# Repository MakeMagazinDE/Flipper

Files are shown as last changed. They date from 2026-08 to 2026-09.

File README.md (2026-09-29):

GitHub Logo

Maker Media GmbH

***

# The Blue Mermaid – Tragbares Flipperspiel

### Ein selbstgebauter Flipper mit ESP32, WS2812B-LEDs, Laser-Lichtschranke und Sound – ein Projekt für Groß und Klein.

Ein tragbares Flipperspiel für ein Festival zu bauen – das allein ist schon eine Herausforderung. Noch schwieriger wird es, wenn die eigenen Kinder mitbauen sollen. Wie das gelingt, wird im Artikel in der Make 5/26 beschrieben.

Im gedruckten Schaltplan (Bild 9, S. 24) sind die Lautsprecher falsch angeschlossen. Sie dürfen nicht mit VCC oder GND verbunden werden. Der DFPlayer Mini hat einen eingebauten Verstärker — beide Lautsprecher werden ausschließlich zwischen SPK_1 und SPK_2 angeschlossen (parallel, ohne externe Stromversorgung). Der korrigierte Schaltplan liegt hier im Repository.

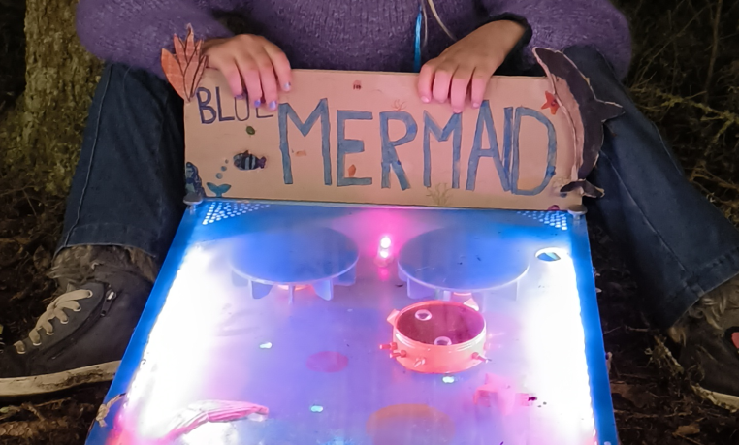
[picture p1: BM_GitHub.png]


Der vollständige Artikel zum Projekt steht in der [Make-Ausgabe 5/26](https://www.heise.de/select/make/2026/5). Hier finden Sie den Arduino-Sketch, die Lasercutter-Vorlagen und die 3D-Druckdateien.

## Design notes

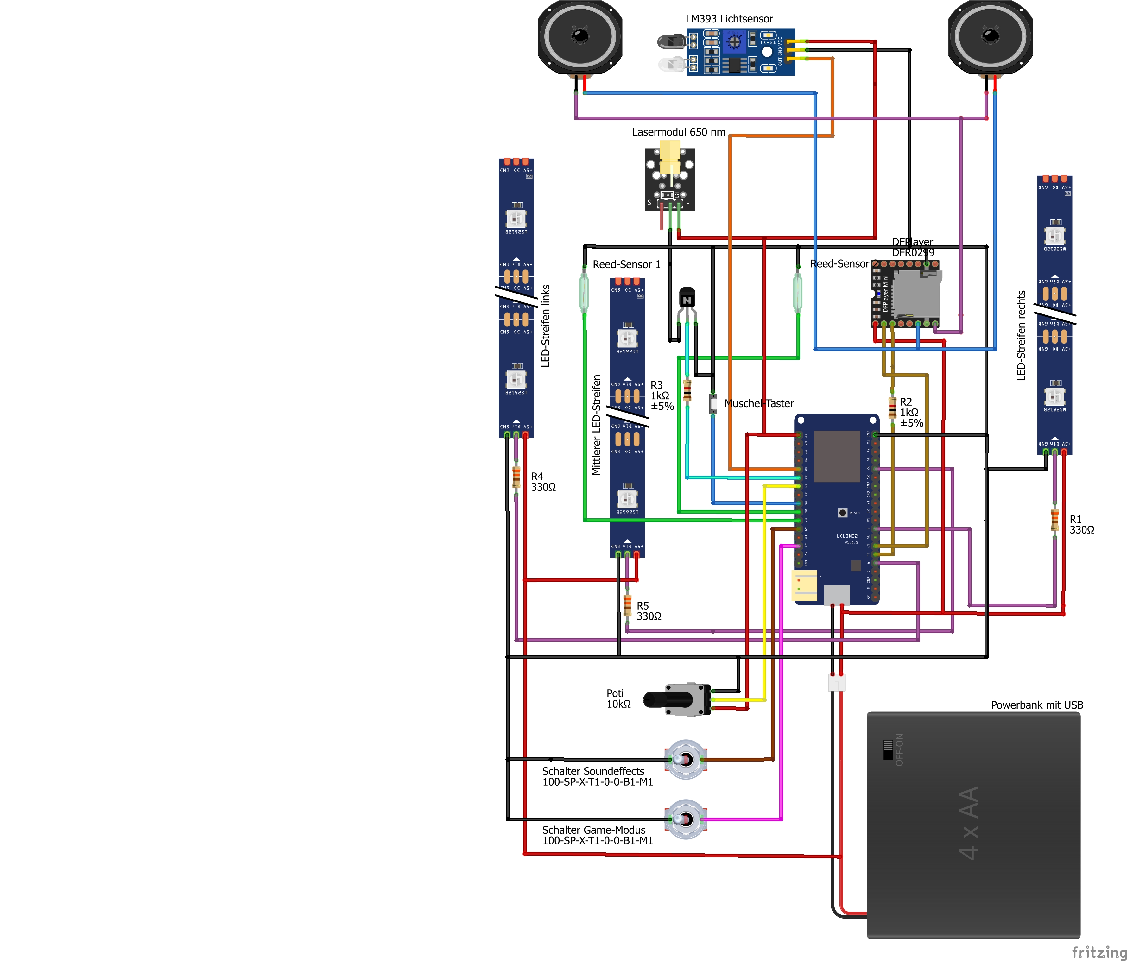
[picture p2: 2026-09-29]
Schaltung-Flipper_Steckplatine_KORRIGIERT.jpg

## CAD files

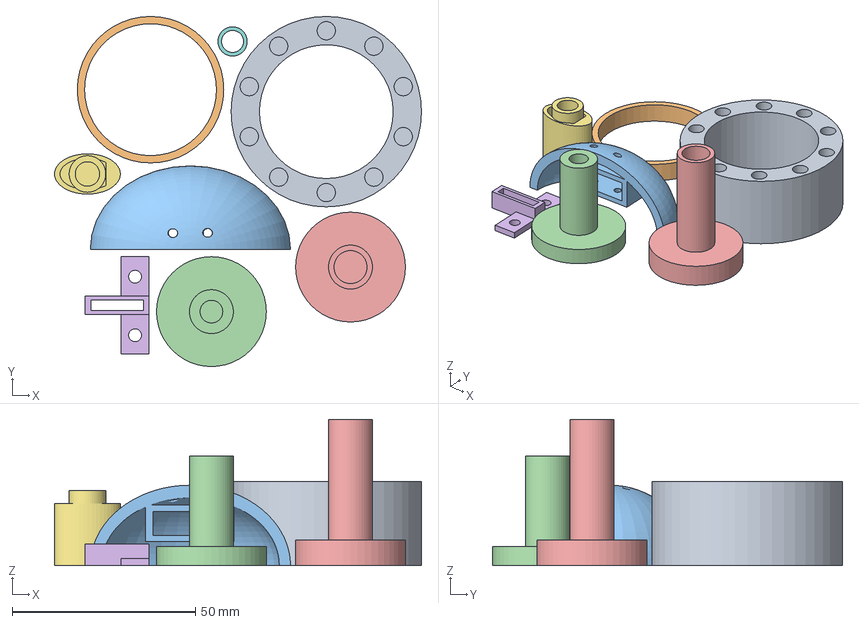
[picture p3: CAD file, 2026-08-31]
Flipper - 3D-Druck - alle Teile zusammen.3mf
100.2 x 95.6 x 40.0 mm
Flipper2.4- ring magnethalter 10 löcher.stl
lautsprecher ring.stl
Muschelhalterung.stl
seppos ding halterung.stl
Flipper Button.stl
Flipper - Reed Sensor Halterung.stl
Laser Halterung.stl
Hülse 6-8 mm 10 hoch.stl

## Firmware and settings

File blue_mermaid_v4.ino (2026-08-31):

// ============================================================
// THE BLUE MERMAID — Portable Pinball Game  v4
// Lolin D32 + DFPlayer Mini
// Main strip: 26 WS2812B  |  Side strips: 35+35 WS2812B
// Total: 96 LEDs
// ============================================================
//
// Libraries (Arduino Library Manager):
//   - FastLED
//   - DFRobotDFPlayerMini
//
// Board: "LOLIN D32" or "ESP32 Dev Module"
//
// SD card (FAT32, files in root):
//   001.mp3  — Seashell chime
//   002.mp3  — Wheel tick slow
//   003.mp3  — Wheel tick medium
//   004.mp3  — Wheel tick fast
//   005.mp3  — Top gate whoosh/splash
//   006.mp3  — Combo fanfare (3+ hits)
//   007.mp3  — Jackpot fanfare (5+ hits)
//
// ============================================================
// WIRING
// ============================================================
//
// POWER — USB power bank:
//   Power bank USB-A 5V  → LED strips VCC (all three)
//   Power bank USB-A GND → LED strips GND (all three)
//   Power bank           → Lolin micro-USB (powers board)
//   Lolin 3V3            → Laser VCC, Light sensor VCC
//
//   Do NOT route LED power through the board!
//   Common GND between power bank, board, and all modules.
//
// MAIN STRIP (26 LEDs, one chain, clockwise from top-right):
//   GPIO 22 → strip DI  (330Ω resistor recommended)
//   Segment order:
//     #1  Upper right corner    3 LEDs  (idx  0– 2)
//     #2  Under right wheel     2 LEDs  (idx  3– 4)
//     #3  Lower middle singles  7 LEDs  (idx  5–11)
//     #4  Bottom right corner   3 LEDs  (idx 12–14)
//     #5  Bottom left corner    3 LEDs  (idx 15–17)
//     #6  Seashell              3 LEDs  (idx 18–20)
//     #7  Under left wheel      2 LEDs  (idx 21–22)
//     #8  Upper left corner     3 LEDs  (idx 23–25)
//
// LEFT SIDE STRIP (35 LEDs, bottom to top):
//   GPIO 4 → strip DI  (330Ω resistor recommended)
//
// RIGHT SIDE STRIP (35 LEDs, bottom to top):
//   GPIO 5 → strip DI  (330Ω resistor recommended)
//
// DFPlayer Mini:
//   GPIO 16 (TX2) → DFPlayer RX  (via 1kΩ resistor!)
//   GPIO 17 (RX2) → DFPlayer TX
//   DFPlayer VCC  → 5V (from power bank)
//   DFPlayer GND  → GND
//   SPK1/SPK2     → 8Ω speaker(s)
//
// SEASHELL SWITCH:
//   GPIO 25 → taster → GND  (INPUT_PULLUP)
//
// WHEEL REED SENSORS (5 magnets, 72° apart):
//   GPIO 26 → left reed sensor → GND
//   GPIO 27 → right reed sensor → GND
//   Mounting: reed long axis tangential, 2–4mm gap.
//
// LASER LICHTSCHRANKE (top gate):
//   GPIO 32 → Light sensor module DO
//   GPIO 33 → 1kΩ → BC337 pin 2 (Base)
//
//   BC337 (TO-92, flat side facing you):
//     Pin 1 (left)   = COLLECTOR → Laser GND wire
//     Pin 2 (center) = BASE     → 1kΩ → GPIO 33
//     Pin 3 (right)  = EMITTER  → GND
//     Laser VCC → 3V3
//
// RESET BUTTON (existing on board):
//   GPIO 2 → taster → GND  (INPUT_PULLUP)
//
// ============================================================

#include <FastLED.h>
#include <DFRobotDFPlayerMini.h>
#include <WiFi.h>
#include <WebServer.h>
#include <DNSServer.h>
#include <Preferences.h>

Preferences prefs;

// ----- Pin definitions -----
#define PIN_MAIN_LED      22
#define PIN_SIDE_L_LED     4
#define PIN_SIDE_R_LED     5
#define PIN_RESET_BTN      2
#define PIN_SEASHELL      25
#define PIN_WHEEL_L       26
#define PIN_WHEEL_R       27
#define PIN_GATE_SENSOR   32
#define PIN_LASER         33
#define DFPLAYER_TX       16
#define DFPLAYER_RX       17
#define PIN_BRIGHT_POT    34    // Potentiometer for brightness (ADC1)
#define PIN_GAME_TOGGLE   13    // Locking switch: ON=playing, OFF=attract
#define PIN_SOUND_TOGGLE  14    // Locking switch: each flip plays next sound

#define SND_EXTRA_START    8    // First extra sound track number on SD card
#define SND_EXTRA_COUNT   10    // Number of extra sound files (008.mp3 - 017.mp3)

// ----- LED counts -----
#define NUM_MAIN          26
#define NUM_SIDE          35    // Per side strip

// ----- Main strip segment indices (clockwise from top-right) -----
#define CORNER_UR_START    0    // #1 Upper right corner
#define CORNER_UR_END      2    //     3 LEDs

#define WHEEL_R_START      3    // #2 Under right wheel
#define WHEEL_R_END        4    //     2 LEDs

#define HOLES_START        5    // #3 Lower middle singles
#define HOLES_END         11    //     7 LEDs

#define CORNER_BR_START   12    // #4 Bottom right corner
#define CORNER_BR_END     14    //     3 LEDs

#define CORNER_BL_START   15    // #5 Bottom left corner
#define CORNER_BL_END     17    //     3 LEDs

#define SHELL_START       18    // #6 Seashell
#define SHELL_END         20    //     3 LEDs

#define WHEEL_L_START     21    // #7 Under left wheel
#define WHEEL_L_END       22    //     2 LEDs

#define CORNER_UL_START   23    // #8 Upper left corner
#define CORNER_UL_END     25    //     3 LEDs

// ----- Sound tracks -----
#define SND_SHELL_CHIME    1
#define SND_WHEEL_SLOW     2
#define SND_WHEEL_MED      3
#define SND_WHEEL_FAST     4
#define SND_TOP_GATE       5
#define SND_COMBO_FANFARE  6
#define SND_JACKPOT        7

// ----- Timing -----
#define COMBO_WINDOW_MS      2500
#define REED_DEBOUNCE_MS       10
#define GATE_DEBOUNCE_MS        5
#define SHELL_DEBOUNCE_MS     200
#define RESET_DEBOUNCE_MS     500
#define WHEEL_TIMEOUT_MS      800

// Wheel speed: ms between reed pulses (5 magnets, 72° apart)
#define WHEEL_FAST_THRESH     150
#define WHEEL_MED_THRESH      300

// Effect durations
#define EFFECT_SHELL_MS       800
#define EFFECT_GATE_MS       1000
#define EFFECT_WHEEL_MS       500
#define EFFECT_COMBO_MS      1500

// Laser blink in attract mode
#define LASER_BLINK_ON_MS    2000
#define LASER_BLINK_OFF_MS    400

// ============================================================
// LED arrays
// ============================================================

CRGB mainLeds[NUM_MAIN];
CRGB sideLeds_L[NUM_SIDE];
CRGB sideLeds_R[NUM_SIDE];

DFRobotDFPlayerMini dfPlayer;
bool dfPlayerReady = false;

// ----- Game state -----
enum GameState { STATE_ATTRACT, STATE_PLAYING, STATE_DEBUG };
GameState gameState = STATE_ATTRACT;
GameState preDebugState = STATE_ATTRACT;
uint16_t score = 0;
unsigned long debugPrintMs = 0;

// ----- Switch state -----
struct SwitchState {
  uint8_t pin;
  bool lastState;
  unsigned long lastChangeMs;
  unsigned long debounceMs;
};

SwitchState sw_shell = { PIN_SEASHELL, HIGH, 0, SHELL_DEBOUNCE_MS };
SwitchState sw_reedL = { PIN_WHEEL_L,  HIGH, 0, REED_DEBOUNCE_MS };
SwitchState sw_reedR = { PIN_WHEEL_R,  HIGH, 0, REED_DEBOUNCE_MS };
SwitchState sw_gate  = { PIN_GATE_SENSOR, HIGH, 0, GATE_DEBOUNCE_MS };
SwitchState sw_reset = { PIN_RESET_BTN,   HIGH, 0, RESET_DEBOUNCE_MS };

// ----- Gate auto-calibration -----
bool gateBeamIntactState = HIGH;

// ----- Physical controls -----
bool lastGameToggle = HIGH;
bool lastSoundToggle = HIGH;
bool gameToggleActive = false;
uint8_t extraSoundIndex = 0;
unsigned long lastPotReadMs = 0;
unsigned long lastGameToggleMs = 0;
unsigned long lastSoundToggleMs = 0;

// ----- Wheel tracking -----
struct WheelTracker {
  unsigned long lastPulseMs;
  unsigned long pulseInterval;
  uint8_t pulseCount;
  uint8_t speedTier;        // 0=stopped, 1=slow, 2=med, 3=fast
  uint8_t lastSoundPlayed;
};

WheelTracker wheelL = { 0, 9999, 0, 0, 0 };
WheelTracker wheelR = { 0, 9999, 0, 0, 0 };

// ----- Combo -----
uint8_t comboCount = 0;
unsigned long lastHitMs = 0;

// ----- Active effects (main strip) -----
struct Effect {
  uint8_t type;   // 0=none 1=shell 2=wheelL 3=wheelR 4=gate 5=combo
  unsigned long startMs;
  unsigned long durationMs;
  uint8_t intensity;
};
#define MAX_EFFECTS 5
Effect effects[MAX_EFFECTS];

// ----- Side strip swoosh state -----
struct Swoosh {
  bool active;
  unsigned long startMs;
  uint8_t hue;
  uint8_t direction;    // 0=top-to-bottom, 1=bottom-to-top
  uint8_t intensity;
  uint16_t durationMs;
  uint8_t sides;        // 0=both, 1=left only, 2=right only
};
#define MAX_SWOOSHES 3
Swoosh swooshes[MAX_SWOOSHES];

// ----- Animation phase -----
uint16_t idlePhase = 0;
bool laserOn = false;
unsigned long laserToggleMs = 0;

// ----- Tunable parameters (adjustable via web, saveable to NVS) -----
uint16_t tuneGateDebounce = GATE_DEBOUNCE_MS;
uint16_t tuneReedDebounce = REED_DEBOUNCE_MS;
uint16_t tuneShellDebounce = SHELL_DEBOUNCE_MS;
uint16_t tuneWheelFast = WHEEL_FAST_THRESH;
uint16_t tuneWheelMed = WHEEL_MED_THRESH;
uint16_t tuneComboWindow = COMBO_WINDOW_MS;
uint8_t  tuneBrightness = 180;
uint16_t tuneLoopDelay = 10;

// ----- Color tuning (HSV hues, 0-255) -----
uint8_t tuneHueSlow   = 145;  // Blue
uint8_t tuneHueMed    = 24;   // Orange
uint8_t tuneHueFast   = 120;  // Cyan
uint8_t tuneHueShell  = 25;   // Warm gold
uint8_t tuneHueGate   = 130;  // Cyan-blue
uint8_t tuneHueIdle   = 140;  // Deep blue
uint8_t tuneHueAttract = 140; // Attract base hue
uint8_t tuneVolume    = 25;   // DFPlayer volume (0-30)

// ----- NVS save/load -----
void saveSettings() {
  prefs.begin("bm", false);
  prefs.putUShort("gateDb", tuneGateDebounce);
  prefs.putUShort("reedDb", tuneReedDebounce);
  prefs.putUShort("shellDb", tuneShellDebounce);
  prefs.putUShort("wFast", tuneWheelFast);
  prefs.putUShort("wMed", tuneWheelMed);
  prefs.putUShort("combo", tuneComboWindow);
  prefs.putUChar("bright", tuneBrightness);
  prefs.putUShort("loopMs", tuneLoopDelay);
  prefs.putUChar("hueSlow", tuneHueSlow);
  prefs.putUChar("hueMed", tuneHueMed);
  prefs.putUChar("hueFast", tuneHueFast);
  prefs.putUChar("hueShell", tuneHueShell);
  prefs.putUChar("hueGate", tuneHueGate);
  prefs.putUChar("hueIdle", tuneHueIdle);
  prefs.putUChar("hueAttr", tuneHueAttract);
  prefs.putUChar("vol", tuneVolume);
  prefs.putUChar("saved", 1);
  prefs.end();
  Serial.println("Settings SAVED to NVS");
}

void loadSettings() {
  prefs.begin("bm", true);
  if (prefs.getUChar("saved", 0) == 1) {
    tuneGateDebounce = prefs.getUShort("gateDb", GATE_DEBOUNCE_MS);
    tuneReedDebounce = prefs.getUShort("reedDb", REED_DEBOUNCE_MS);
    tuneShellDebounce = prefs.getUShort("shellDb", SHELL_DEBOUNCE_MS);
    tuneWheelFast = prefs.getUShort("wFast", WHEEL_FAST_THRESH);
    tuneWheelMed = prefs.getUShort("wMed", WHEEL_MED_THRESH);
    tuneComboWindow = prefs.getUShort("combo", COMBO_WINDOW_MS);
    tuneBrightness = prefs.getUChar("bright", 180);
    tuneLoopDelay = prefs.getUShort("loopMs", 10);
    tuneHueSlow = prefs.getUChar("hueSlow", 145);
    tuneHueMed = prefs.getUChar("hueMed", 24);
    tuneHueFast = prefs.getUChar("hueFast", 120);
    tuneHueShell = prefs.getUChar("hueShell", 25);
    tuneHueGate = prefs.getUChar("hueGate", 130);
    tuneHueIdle = prefs.getUChar("hueIdle", 140);
    tuneHueAttract = prefs.getUChar("hueAttr", 140);
    tuneVolume = prefs.getUChar("vol", 25);
    Serial.println("Settings LOADED from NVS");
  } else {
    Serial.println("No saved settings, using defaults");
  }
  prefs.end();

  // Apply loaded values
  FastLED.setBrightness(tuneBrightness);
  sw_gate.debounceMs = tuneGateDebounce;
  sw_reedL.debounceMs = tuneReedDebounce;
  sw_reedR.debounceMs = tuneReedDebounce;
  sw_shell.debounceMs = tuneShellDebounce;
}

// ----- Gate interrupt (catches fast ball crossings) -----
volatile bool gateISRfired = false;
volatile unsigned long gateISRtime = 0;

void IRAM_ATTR gateISR() {
  gateISRfired = true;
  gateISRtime = millis();
}

// ============================================================
// WiFi Captive Portal (debug via phone)
// ============================================================

WebServer webServer(80);
DNSServer dnsServer;
const byte DNS_PORT = 53;

unsigned long webHitShell = 0;
unsigned long webHitWheelL = 0;
unsigned long webHitWheelR = 0;
unsigned long webHitGate = 0;
bool webLaserOverride = false;
bool webLaserState = false;

void setupWiFi() {
  WiFi.softAP("BlueMermaid");
  delay(100);
  dnsServer.start(DNS_PORT, "*", WiFi.softAPIP());

  // Captive portal detection endpoints
  webServer.on("/generate_204", []() {
    webServer.sendHeader("Location", "http://192.168.4.1/");
    webServer.send(302, "text/plain", "");
  });
  webServer.on("/hotspot-detect.html", []() {
    webServer.sendHeader("Location", "http://192.168.4.1/");
    webServer.send(302, "text/plain", "");
  });
  webServer.on("/connecttest.txt", []() {
    webServer.sendHeader("Location", "http://192.168.4.1/");
    webServer.send(302, "text/plain", "");
  });
  webServer.on("/redirect", []() {
    webServer.sendHeader("Location", "http://192.168.4.1/");
    webServer.send(302, "text/plain", "");
  });
  webServer.on("/success.txt", []() {
    webServer.send(200, "text/plain", "success");
  });

  webServer.on("/", handleWebRoot);
  webServer.on("/data", handleWebData);
  webServer.on("/set", handleWebSet);
  webServer.on("/laser/on",  []() { webLaserOverride=true; webLaserState=true;  setLaser(true);  webServer.send(200, "text/plain", "on"); });
  webServer.on("/laser/off", []() { webLaserOverride=true; webLaserState=false; setLaser(false); webServer.send(200, "text/plain", "off"); });
  webServer.on("/laser/auto", []() { webLaserOverride=false; webServer.send(200, "text/plain", "auto"); });
  webServer.on("/save", []() { saveSettings(); webServer.send(200, "text/plain", "saved"); });
  webServer.on("/reset", []() {
    webHitShell=0; webHitWheelL=0; webHitWheelR=0; webHitGate=0;
    webServer.send(200, "text/plain", "ok");
  });
  webServer.onNotFound([]() {
    webServer.sendHeader("Location", "http://192.168.4.1/");
    webServer.send(302, "text/plain", "");
  });
  webServer.begin();
  Serial.print("WiFi AP: BlueMermaid @ ");
  Serial.println(WiFi.softAPIP());
}

void handleWebRoot() {
  String html = R"rawliteral(
<!DOCTYPE html>
<html>
<head>
<meta charset="utf-8">
<meta name="viewport" content="width=device-width, initial-scale=1">
<title>Blue Mermaid</title>
<style>
* { box-sizing: border-box; margin: 0; padding: 0; }
body {
  font-family: -apple-system, Arial, sans-serif;
  background: #0a1628; color: #e0e8f0;
  padding: 12px; max-width: 420px; margin: 0 auto;
}
h1 { color: #4fc3f7; font-size: 18px; text-align: center; margin-bottom: 10px; }
.card {
  background: #162040; border-radius: 10px;
  padding: 12px; margin-bottom: 10px;
  border: 1px solid #2a3a5c;
}
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
void loop() {
  unsigned long now = millis();

  dnsServer.processNextRequest();
  webServer.handleClient();

  // --- Potentiometer brightness (read every 100ms, smoothed) ---
  if ((now - lastPotReadMs) > 100) {
    lastPotReadMs = now;
    int raw = analogRead(PIN_BRIGHT_POT);
    uint8_t potBright = map(raw, 0, 4095, 10, 255);
    // Smooth: only update if change is significant (avoids ADC noise flicker)
    if (abs((int)potBright - (int)tuneBrightness) > 5) {
      tuneBrightness = potBright;
      FastLED.setBrightness(tuneBrightness);
    }
  }

  // --- Game toggle switch (locking switch, 50ms debounce) ---
  bool curGame = digitalRead(PIN_GAME_TOGGLE);
  if (curGame != lastGameToggle && (now - lastGameToggleMs) > 50) {
    lastGameToggle = curGame;
    lastGameToggleMs = now;
    gameToggleActive = (curGame == LOW);
    if (gameToggleActive && gameState == STATE_ATTRACT) {
      score = 0;
      comboCount = 0;
      lastHitMs = 0;
      wheelL = { 0, 9999, 0, 0, 0 };
      wheelR = { 0, 9999, 0, 0, 0 };
      for (int i = 0; i < MAX_EFFECTS; i++) effects[i].type = 0;
      for (int i = 0; i < MAX_SWOOSHES; i++) swooshes[i].active = false;
      gameState = STATE_PLAYING;
      setLaser(true);
    } else if (!gameToggleActive && gameState == STATE_PLAYING) {
      gameState = STATE_ATTRACT;
      setLaser(false);
    }
  }

  // --- Sound toggle switch (locking switch, 50ms debounce) ---
  bool curSound = digitalRead(PIN_SOUND_TOGGLE);
  if (curSound != lastSoundToggle && (now - lastSoundToggleMs) > 50) {
    lastSoundToggle = curSound;
    lastSoundToggleMs = now;
    if (dfPlayerReady) dfPlayer.volume(tuneVolume);
    playSound(SND_EXTRA_START + extraSoundIndex);
    extraSoundIndex = (extraSoundIndex + 1) % SND_EXTRA_COUNT;
  }

  checkResetButton(now);
  updateLaser(now);

  if (gameState == STATE_DEBUG) {
    renderDebug(now);
    FastLED.show();
    delay(10);
    return;
  }

  if (gameState == STATE_PLAYING) {
    checkSeashell(now);
    checkReed(now, sw_reedL, wheelL, true);
    checkReed(now, sw_reedR, wheelR, false);
    checkTopGate(now);
    updateWheelTimeout(now, wheelL);
    updateWheelTimeout(now, wheelR);

    if (comboCount > 0 && (now - lastHitMs) > tuneComboWindow) {
      comboCount = 0;
    }
  }

  renderMainStrip(now);
  renderSideStrips(now);
  FastLED.show();
  delay(tuneLoopDelay);
}

// ============================================================
// Game control
// ============================================================

void checkResetButton(unsigned long now) {
  if (debouncePress(sw_reset, now)) {

    if (gameState == STATE_DEBUG) {
      // Exit debug → go to attract
      gameState = STATE_ATTRACT;
      setLaser(false);
      Serial.println(">>> DEBUG OFF — ATTRACT MODE <<<");
      return;
    }

    if (gameState == STATE_ATTRACT) {
      // Short press in attract: check if held for 2s → debug
      // For now: first press = start game
      score = 0;
      comboCount = 0;
      lastHitMs = 0;
      wheelL = { 0, 9999, 0, 0, 0 };
      wheelR = { 0, 9999, 0, 0, 0 };
      for (int i = 0; i < MAX_EFFECTS; i++) effects[i].type = 0;
      for (int i = 0; i < MAX_SWOOSHES; i++) swooshes[i].active = false;

      gameState = STATE_PLAYING;
      webLaserOverride = false;
      setLaser(true);
      gateISRfired = false;
      Serial.println(">>> GAME START <<<");

      // Startup flash
      fill_solid(mainLeds,   NUM_MAIN, CRGB(0, 60, 90));
      fill_solid(sideLeds_L, NUM_SIDE, CRGB(0, 40, 80));
      fill_solid(sideLeds_R, NUM_SIDE, CRGB(0, 40, 80));
      FastLED.show();
      delay(400);

    } else if (gameState == STATE_PLAYING) {
      // Press during game = reset score
      score = 0;
      comboCount = 0;
      lastHitMs = 0;
      Serial.println(">>> SCORE RESET <<<");
    }
  }

  // Long press detection: hold button for 2 seconds → toggle debug
  static unsigned long btnHeldSince = 0;
  static bool btnWasHeld = false;
  bool btnDown = (digitalRead(PIN_RESET_BTN) == LOW);

  if (btnDown && btnHeldSince == 0) {
    btnHeldSince = now;
    btnWasHeld = false;
  } else if (btnDown && !btnWasHeld && (now - btnHeldSince) > 2000) {
    btnWasHeld = true;
    if (gameState != STATE_DEBUG) {
      preDebugState = gameState;
      gameState = STATE_DEBUG;
      setLaser(true);
      Serial.println(">>> DEBUG MODE ON <<<");
      Serial.println("    Inputs shown on LEDs + Serial.");
      Serial.println("    Press button to exit.");
    }
  } else if (!btnDown) {
    btnHeldSince = 0;
  }
}

// ============================================================
// Laser
// ============================================================

void setLaser(bool on) {
  laserOn = on;
  digitalWrite(PIN_LASER, on ? HIGH : LOW);
  gateISRfired = false;  // Ignore interrupt caused by laser toggle
}

void updateLaser(unsigned long now) {
  if (webLaserOverride) {
    if (laserOn != webLaserState) setLaser(webLaserState);
    return;
  }
  if (gameState == STATE_PLAYING) {
    if (!laserOn) setLaser(true);
    return;
  }
  // Attract: blink
  if (laserOn && (now - laserToggleMs) > LASER_BLINK_ON_MS) {
    setLaser(false);
    laserToggleMs = now;
  } else if (!laserOn && (now - laserToggleMs) > LASER_BLINK_OFF_MS) {
    setLaser(true);
    laserToggleMs = now;
  }
}

// ============================================================
// Switch reading
// ============================================================

bool debouncePress(SwitchState &sw, unsigned long now) {
  bool cur = digitalRead(sw.pin);
  if (cur != sw.lastState && (now - sw.lastChangeMs) > sw.debounceMs) {
    sw.lastChangeMs = now;
    bool wasHigh = sw.lastState;
    sw.lastState = cur;
    return (wasHigh && !cur);  // Falling edge
  }
  return false;
}

bool debounceGate(SwitchState &sw, unsigned long now) {
  bool cur = digitalRead(sw.pin);
  if (cur != sw.lastState && (now - sw.lastChangeMs) > sw.debounceMs) {
    sw.lastChangeMs = now;
    bool wasIntact = (sw.lastState == gateBeamIntactState);
    sw.lastState = cur;
    return (wasIntact && cur != gateBeamIntactState);
  }
  return false;
}

// ============================================================
// Hit registration & combo
// ============================================================

void registerHit(unsigned long now, uint16_t points) {
  score += points;
  if ((now - lastHitMs) < tuneComboWindow) {
    comboCount++;
  } else {
    comboCount = 1;
  }
  lastHitMs = now;

  Serial.printf("Score: %d  Combo: x%d\n", score, comboCount);

  if (comboCount >= 5) {
    triggerEffect(5, EFFECT_COMBO_MS, 255, now);
    triggerSwoosh(1, 160, 255, 1200, 0, now);  // Bottom-to-top rainbow
    playSound(SND_JACKPOT);
    Serial.println(">>> JACKPOT <<<");
  } else if (comboCount >= 3) {
    triggerEffect(5, EFFECT_COMBO_MS, 200, now);
    triggerSwoosh(0, 128, 200, 800, 0, now);   // Top-to-bottom
    playSound(SND_COMBO_FANFARE);
    Serial.println(">> COMBO <<");
  }
}

// ============================================================
// Input handlers
// ============================================================

void checkSeashell(unsigned long now) {
  if (debouncePress(sw_shell, now)) {
    Serial.println("Seashell!");
    triggerEffect(1, EFFECT_SHELL_MS, 255, now);
    playSound(SND_SHELL_CHIME);
    registerHit(now, 50);
    webHitShell++;
  }
}
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
